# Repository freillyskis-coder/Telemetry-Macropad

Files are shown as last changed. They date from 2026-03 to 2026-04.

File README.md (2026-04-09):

# Telemetry-Macropad
This is a place where I store all of my files for my macropad that has an accelerometer, display, and lights that will show telemetry information for racing.

### What It Does
This macropad has a computer, display, accelerometer, a few lights, and 3 keys. The accelerometer is used to measure acceleration in different directions (duh). That information gets used to display which direction it is accelerating in a traction-circle style display, or in plain number format, on the screen. The lights also indicate what direction the board is accelerating, with one pointing in each cardinal direction for the device. The lights each have two functions, requiring a long or short press. They go like this:
- Switch modes on the display (trac circle, current acceleration numbers, etc) (Short) / Set brightness (Long)
- Recalibration (Short) / Switch Units (g’s vs m/s) (Long)
- Freezes max acceleration (Short) / Reset acceleration (size of the traction circle) (Long)
  
### Why I Built This
I have seen traction circles be used in racing simulators to assist the driver. However, I had never seen one in a real car. I thought it would be really cool to try my hand at designing a device that could display information relevant to racing. In the future, I may add new features such as data collection, slip warnings, etc. 

### Challenges
I haven't done that much design work myself, so this was full of new experiences for me. I have used onshape for 3d cad work before, so it was fun learning how to use fusion (they were pretty similar, at least for what I was doing). 
I also enjoyed learning how to use the KiCAD software. I've used Rapidharness before for electrical work, but it was so cool and different designing a PCB. One of the biggest challenges was the coding, as I've only used Java for my compsci class, and figuring out how to use Github (it required a lot of youtube tutorials and headscratching). Overall, I persisted through and I gained a lot of valuable skills and had a good time!

### Designs
Schematic            |  PCB         |   Case    |   
:-------------------------:|:-------------------------:|:-------------------------:|
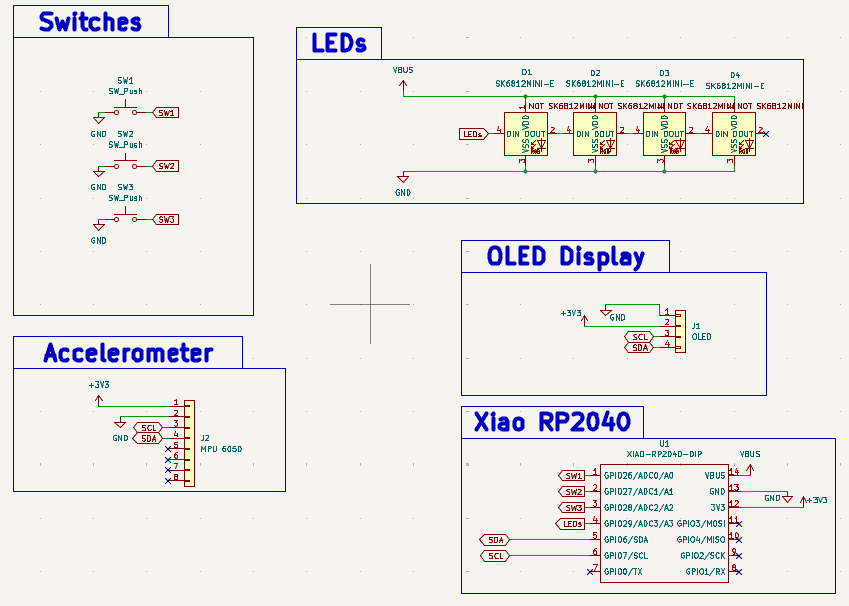
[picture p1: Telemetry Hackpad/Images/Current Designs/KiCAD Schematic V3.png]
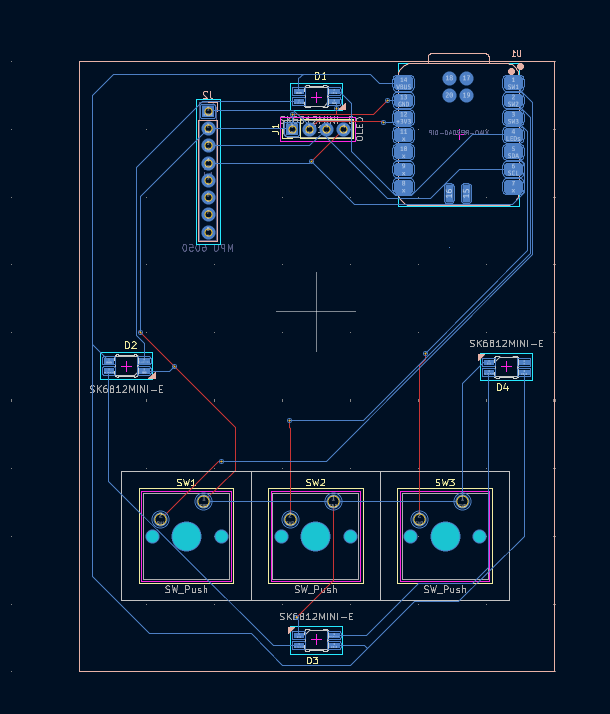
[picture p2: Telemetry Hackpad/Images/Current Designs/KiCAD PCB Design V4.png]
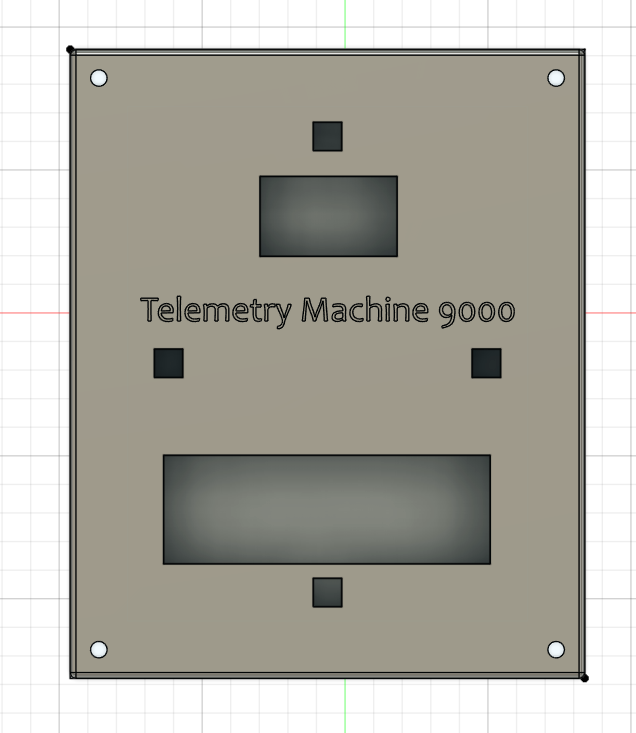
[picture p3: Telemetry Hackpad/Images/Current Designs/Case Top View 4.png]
  |    |   

# Overall Hackpad:

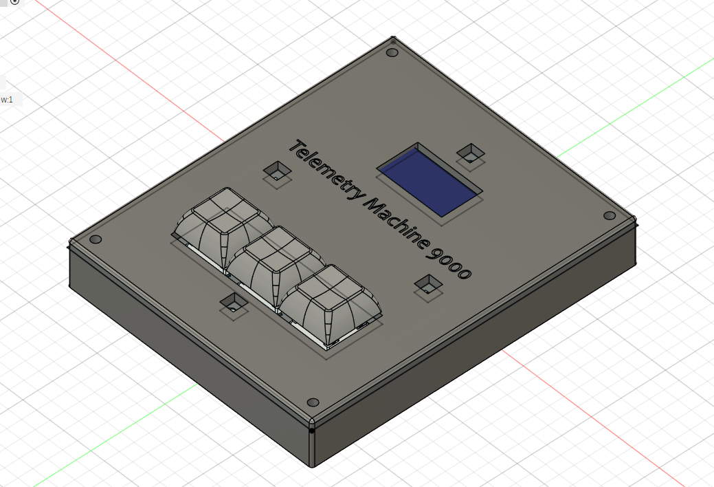
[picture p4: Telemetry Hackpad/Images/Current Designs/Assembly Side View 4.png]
 

### Bill Of Materials

- [4 x SK6812MINI-E](https://www.digikey.com/en/products/detail/adafruit-industries-llc/4960/14302512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) - lights, $2.95
- [1 x XIAO RP2040 DIP](https://www.seeedstudio.com/XIAO-RP2040-v1-0-p-5026.html) - computer, $3.99
- [3 x Cherry MX Switches](https://mechanicalkeyboards.com/products/cherry-mx2a-silent-red-45g-linear?variant=48014625177900) - switches $0.40
- [3 x DSA Black Keycaps](https://thepihut.com/products/black-dsa-keycaps-for-mx-compatible-switches-10-pack) - keycaps (10 pack) $5.80
- [4 x M3x3mm heatset inserts](https://www.adafruit.com/product/4256) - inserts, $5.95 
- [4 x M3x10mm screws](https://www.amazon.com/Screws-Assortment-Machine-Washers-Phillips/dp/B0G9HDWD3K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)   - screws, $3.99
- My PCB, printed
- My 3D printed case

I have an accelerometer and 0.96" display in my designs, but I am not requesting them as I know it they not a part of the kit. I will pay for this myself.
- [1 x MPU 6050](https://www.alibaba.com/product-detail/TZT-1Set-IIC-I2C-GY-521_1600855862949.html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) - accelerometer, $1.45
- [1 x SSD1306 OLED](https://www.alibaba.com/product-detail/0-96-128x64-I2C-IIC-Serial_1601221974195.html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) - display, $2.50

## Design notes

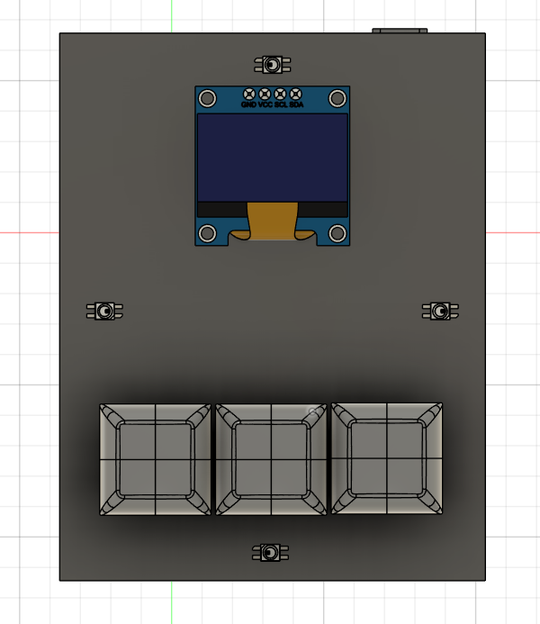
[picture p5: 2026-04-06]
Telemetry Hackpad/Images/Current Designs/PCB Top View 4.png

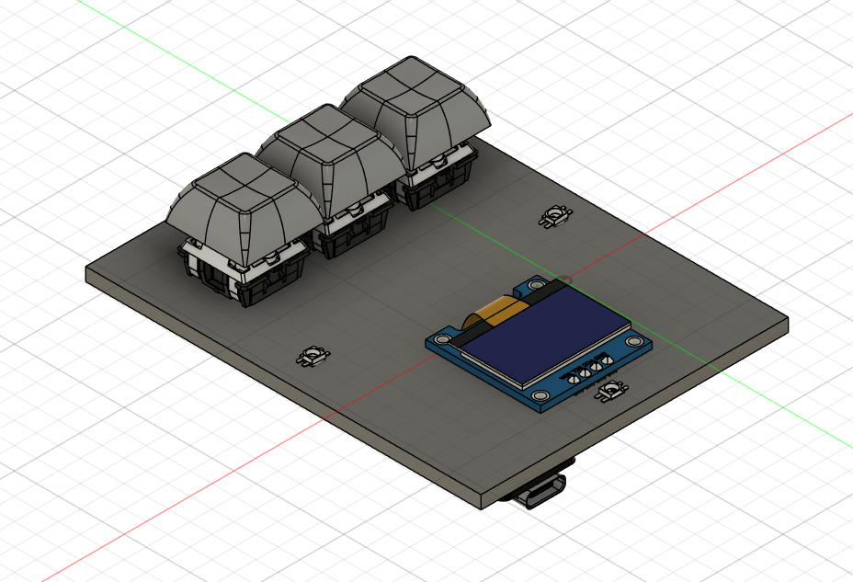
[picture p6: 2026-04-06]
Telemetry Hackpad/Images/Current Designs/PCB Side View 4.png

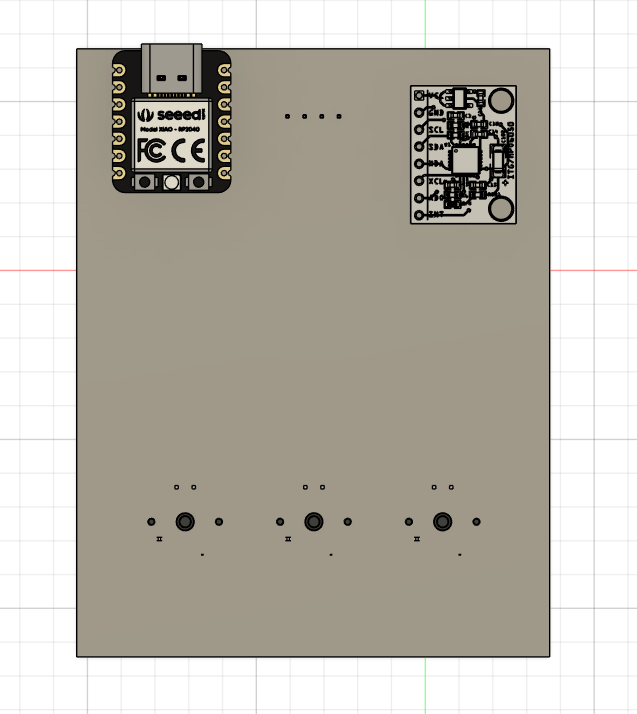
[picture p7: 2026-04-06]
Telemetry Hackpad/Images/Current Designs/PCB Bottom View 4.png

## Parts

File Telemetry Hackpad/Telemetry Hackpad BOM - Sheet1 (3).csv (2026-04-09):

Part | Cost | Link
4 x SK6812MINI-E - lights | $2.95 | https://www.digikey.com/en/products/detail/adafruit-industries-llc/4960/14302512?gclsrc=aw.ds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
XIAO RP2040 DIP - computer | $3.99 | https://www.seeedstudio.com/XIAO-RP2040-v1-0-p-5026.html
3 x Cherry MX Switches - switches | $0.40 | https://mechanicalkeyboards.com/products/cherry-mx2a-silent-red-45g-linear?variant=48014625177900
3 x DSA Black Keycaps - keycaps (10 pack) | $5.80 | https://thepihut.com/products/black-dsa-keycaps-for-mx-compatible-switches-10-pack
4 x M3x3mm heatset inserts | $5.95 | https://www.adafruit.com/product/4256
4 x M3x10mm screws - screws | $3.99 | https://www.amazon.com/Screws-Assortment-Machine-Washers-Phillips/dp/B0G9HDWD3K?s=industrial
My PCB, printed
My 3D printed case
Total: | $23.08
I will purchase the accelerometer myself and display myself because they are not in the kit
MPU 6050 - accelerometer | $1.45 | https://www.alibaba.com/product-detail/TZT-1Set-IIC-I2C-GY-521_1600855862949.html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
SSD1306 OLED - display | $2.50 | https://www.alibaba.com/product-detail/0-96-128x64-I2C-IIC-Serial_1601221974195.html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

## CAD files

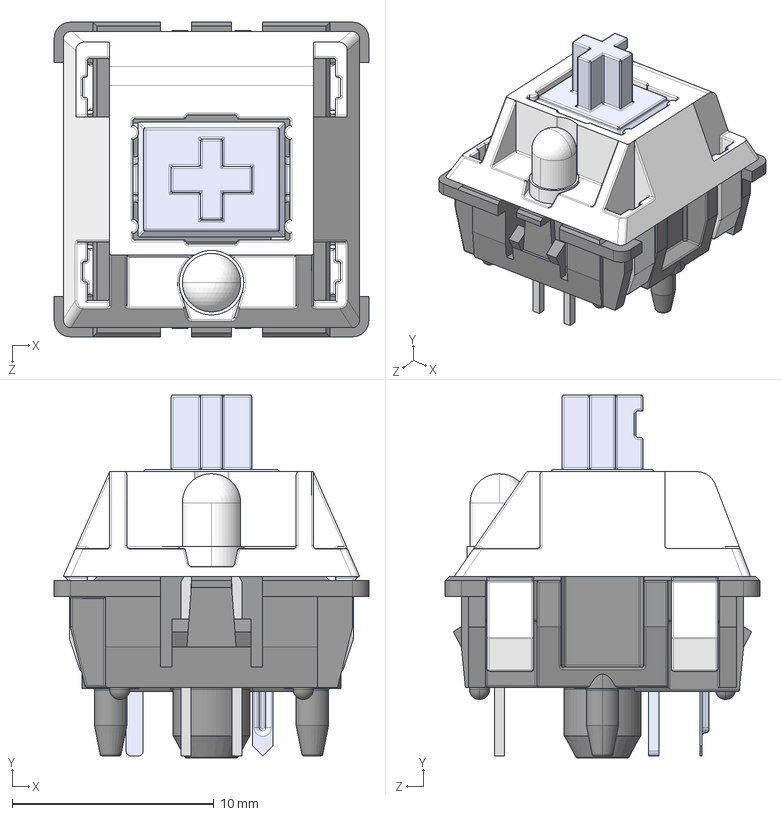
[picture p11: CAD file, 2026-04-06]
Telemetry Hackpad/CAD/Electronics CAD Models/Cherry MX/Cherry MX.STEP
15.6 x 18.0 x 15.6 mm
Bottom
Pulsador
Top
Pieza5^Cherry MX
Pin1
Pin2
Led 3mm_trans

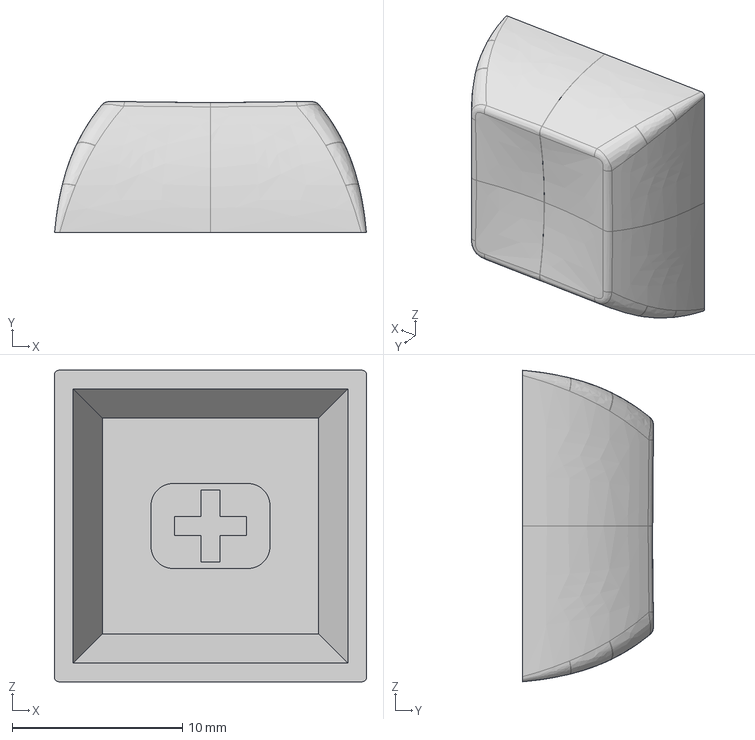
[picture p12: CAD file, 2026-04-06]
Telemetry Hackpad/CAD/Electronics CAD Models/DSA Keycap/DSA_Keycap_CherryMX.step
18.3 x 7.69 x 18.3 mm

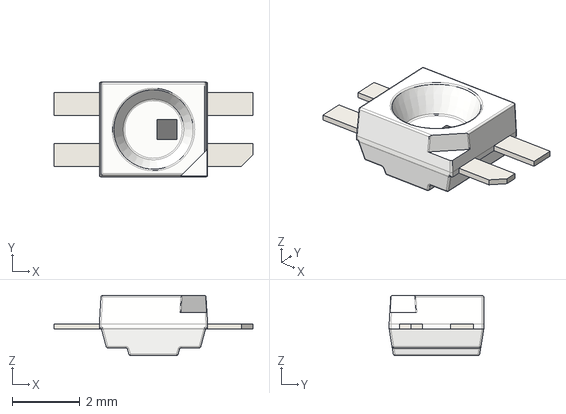
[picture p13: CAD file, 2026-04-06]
Telemetry Hackpad/CAD/Electronics CAD Models/SK6812MINI-E/LED_SK6812MINI-E.step
5.88 x 2.80 x 1.78 mm

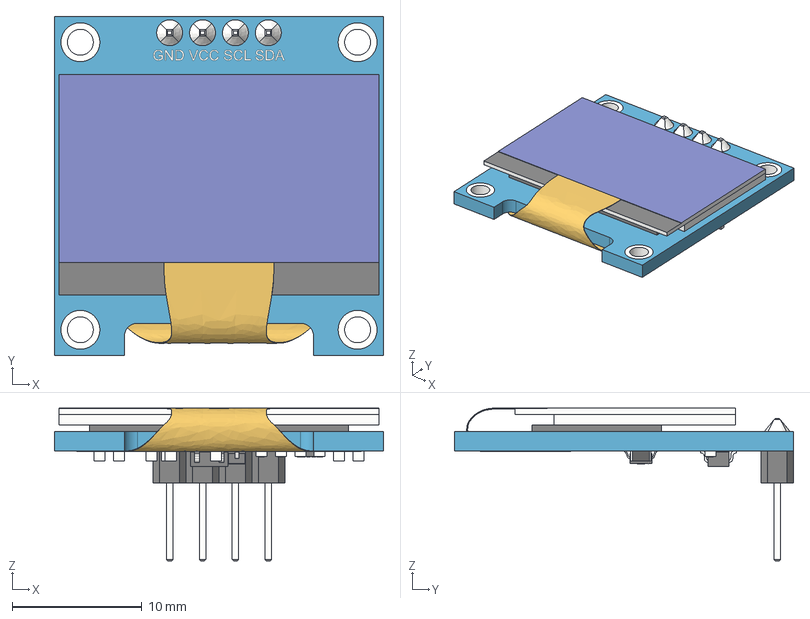
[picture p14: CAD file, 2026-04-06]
Telemetry Hackpad/CAD/Electronics CAD Models/SSD1306 OLED/SSD1306_OLED_Display(128x64).step
25.4 x 26.2 x 11.8 mm
board
screen
pin_header
soldering
smd_capacitor
smd_capacitor (1)
914_smd_resistor
472_smd_resistor x 3
t4_smd_diode
smd_capacitor (2)
smd_capacitor (3)
smd_capacitor (4)
smd_capacitor (5)
smd_capacitor (6)
472_smd_resistor (1)
SOT-23_XC6206 v3
smd_capacitor (7)
flat_cable

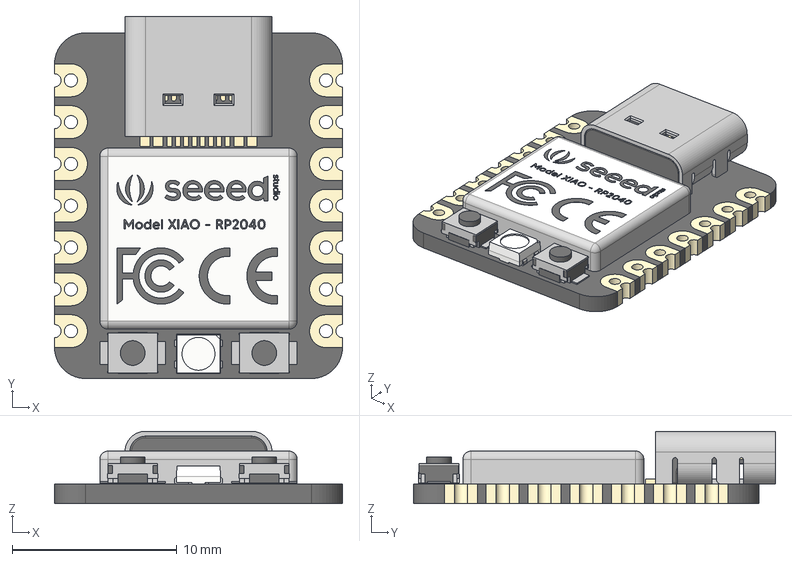
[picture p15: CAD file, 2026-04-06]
Telemetry Hackpad/CAD/Electronics CAD Models/XIAO RP2040/Seeed Studio XIAO RP2040/Seeed Studio XIAO RP2040 v26.step
17.5 x 22.0 x 4.40 mm
type-c v2
smd_button v3
DOUT
DIN
VSS
VDD
smd_button v3(Mirror)

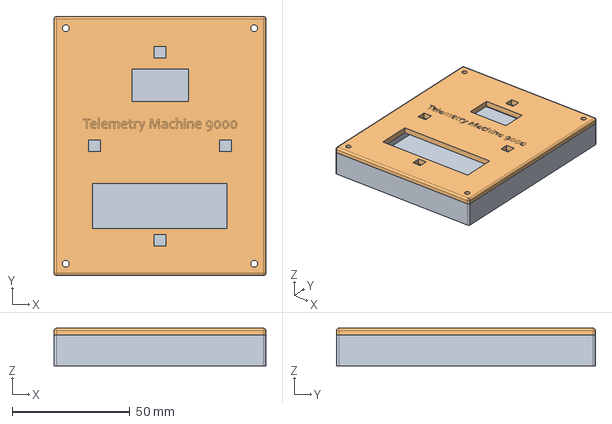
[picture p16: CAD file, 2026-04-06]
Telemetry Hackpad/CAD/Individual Parts/Telemetry Case.step
90.0 x 110.0 x 16.0 mm

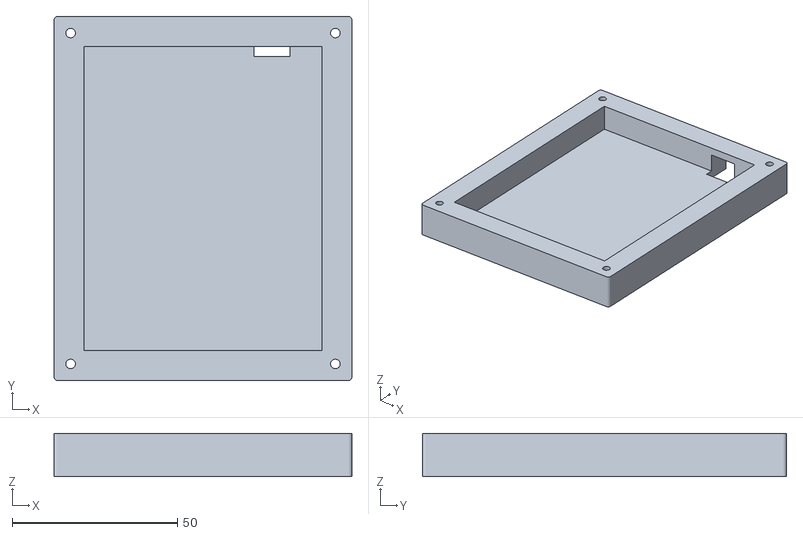
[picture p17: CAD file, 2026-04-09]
Telemetry Hackpad/Production/Bottom Case.stl
90.0 x 110.0 x 13.0

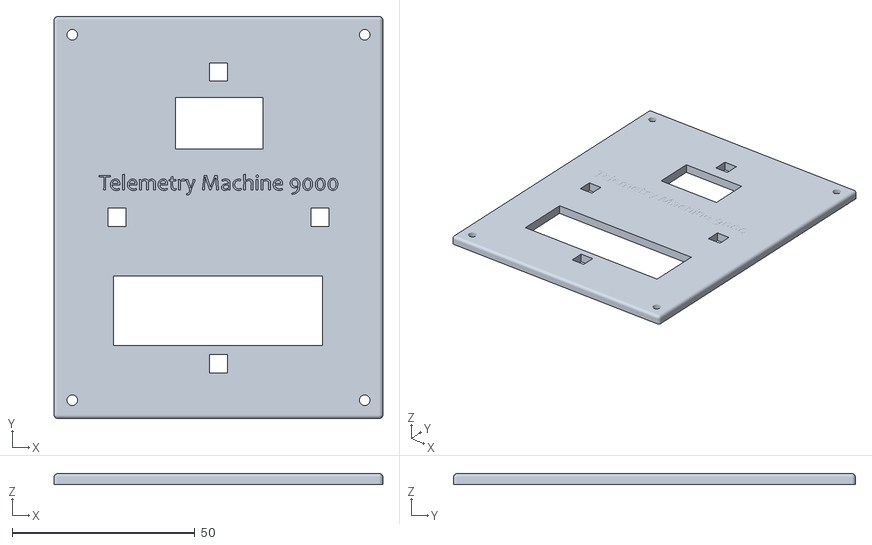
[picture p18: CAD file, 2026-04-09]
Telemetry Hackpad/Production/Top Case.stl
90.0 x 110.0 x 3.00

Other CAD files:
Telemetry Hackpad/CAD/Electronics CAD Models/DSA Keycap/Keycap_adjusted v39.f3d
Telemetry Hackpad/CAD/Electronics CAD Models/SSD1306 OLED/SSD1306_OLED_Display(128x64).f3d
Telemetry Hackpad/CAD/Electronics CAD Models/XIAO RP2040/Seeed Studio XIAO RP2040/Seeed Studio XIAO RP2040 v26.f3d
Telemetry Hackpad/CAD/Individual Parts/Telemetry Case.f3d

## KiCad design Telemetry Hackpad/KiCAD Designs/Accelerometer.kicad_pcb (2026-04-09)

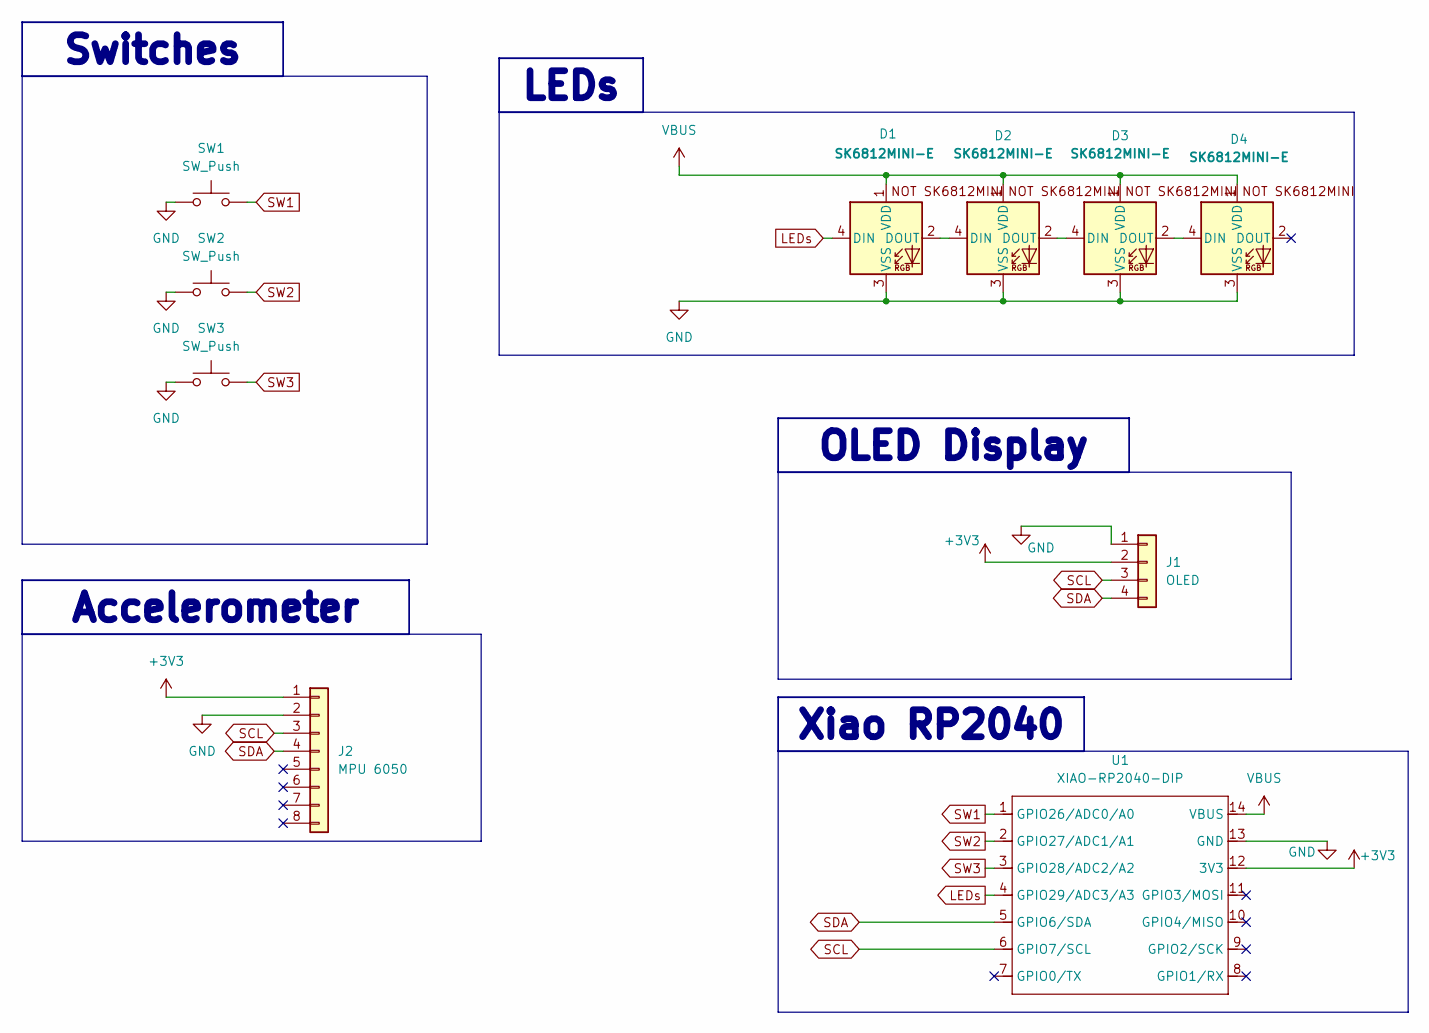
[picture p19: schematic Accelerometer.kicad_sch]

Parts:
D1, D2, D3, D4: SK6812MINI-E; SK6812MINI-E_fixed
J1: OLED; PinHeader_1x04_P2.54mm_Vertical
J2: MPU 6050; PinHeader_1x08_P2.54mm_Vertical
SW1, SW2, SW3: SW_Push; SW_Cherry_MX_1.00u_PCB
U1: XIAO-RP2040-DIP; XIAO-RP2040-SMD

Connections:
+3V3: J1.2 (VDD), J2.1 (VCC), U1.12 (3V3)
GND: D1.3 (VSS), D2.3 (VSS), D3.3 (VSS), D4.3 (VSS), J1.1 (GND), J2.2 (GND), SW1.1, SW2.1, SW3.1, U1.13 (GND)
LEDs: D1.4 (DIN), U1.4 (GPIO29/ADC3/A3)
unnamed: D1.2 (DOUT), D2.4 (DIN)
unnamed: D2.2 (DOUT), D3.4 (DIN)
unnamed: D3.2 (DOUT), D4.4 (DIN)
SCL: J1.3 (SCL), J2.3 (SCL), U1.6 (GPIO7/SCL)
SDA: J1.4 (SDA), J2.4 (SDA), U1.5 (GPIO6/SDA)
SW1: SW1.2, U1.1 (GPIO26/ADC0/A0)
SW2: SW2.2, U1.2 (GPIO27/ADC1/A1)
SW3: SW3.2, U1.3 (GPIO28/ADC2/A2)
VBUS: D1.1 (VDD), D2.1 (VDD), D3.1 (VDD), D4.1 (VDD), U1.14 (VBUS)

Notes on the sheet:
Accelerometer
LEDs
Xiao RP2040
Switches
OLED Display

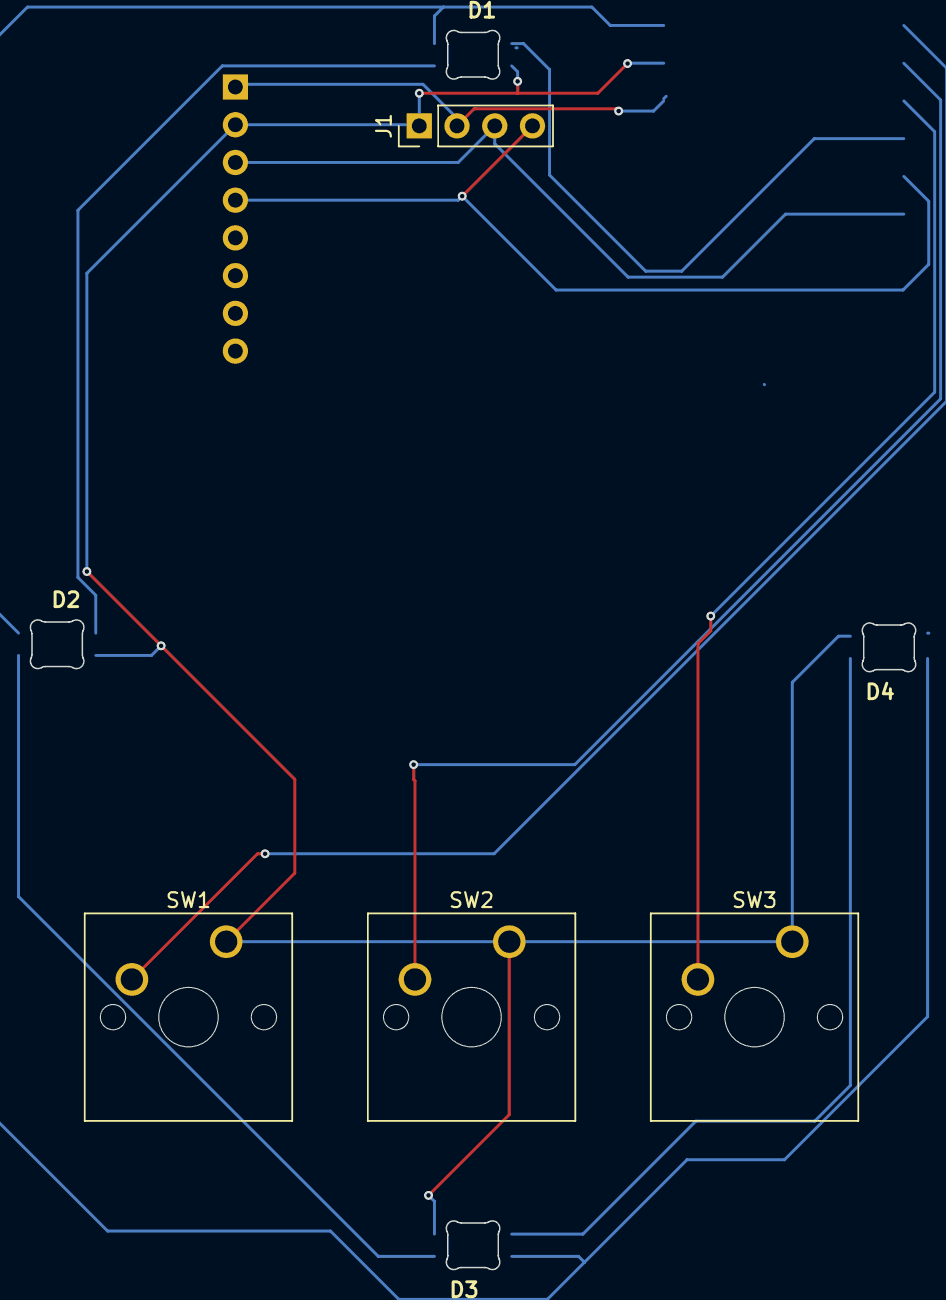
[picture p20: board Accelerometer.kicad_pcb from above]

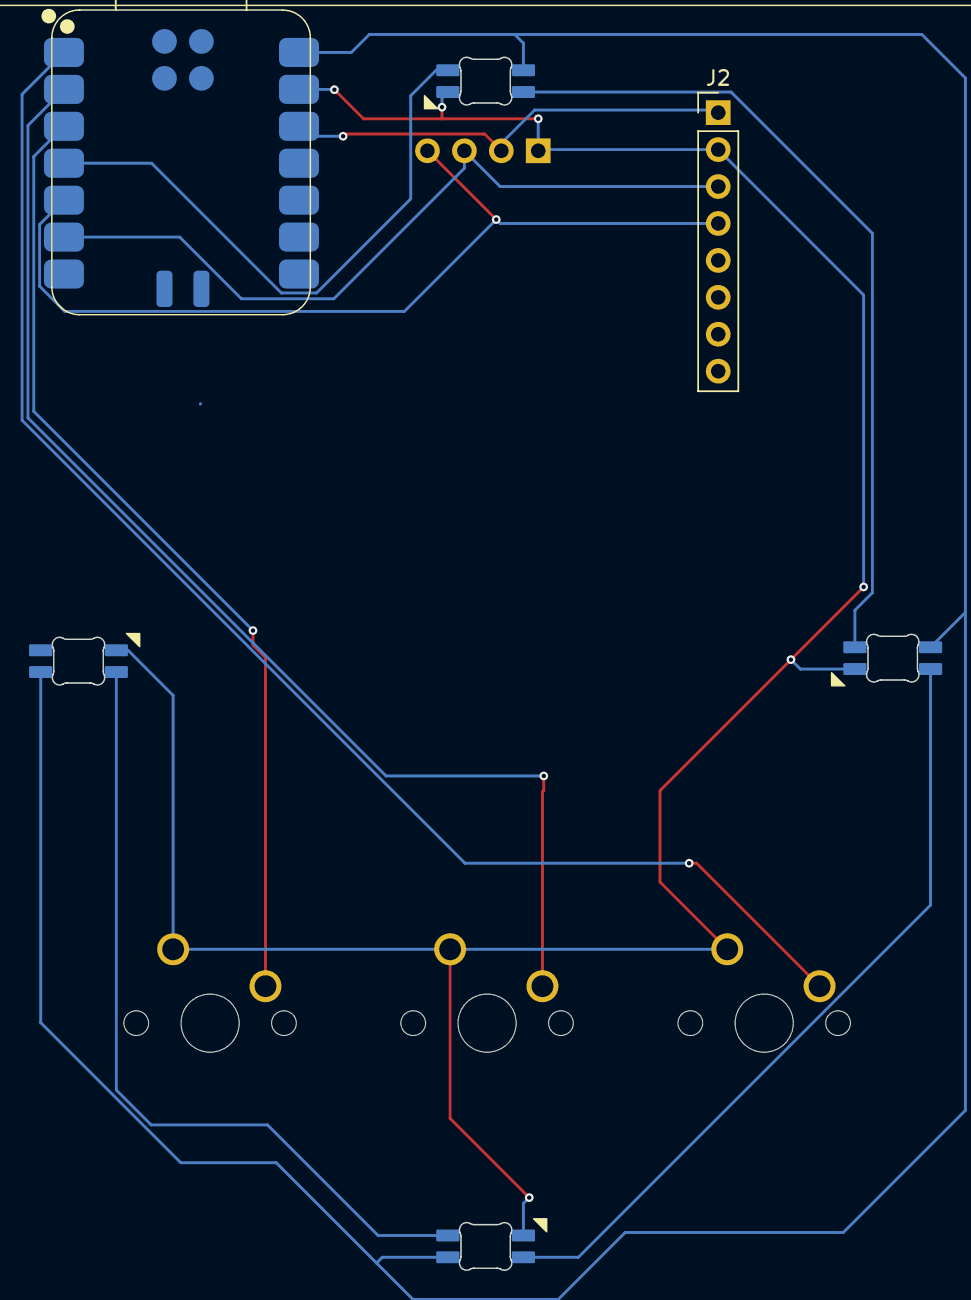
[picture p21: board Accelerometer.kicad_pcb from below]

Board: 2 copper layers, 10 parts (2 on the bottom side), 12 nets.

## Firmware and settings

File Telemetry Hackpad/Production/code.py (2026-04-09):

code.py
# --- Imports ---
import board
import busio
import time
import neopixel
import digitalio
import math
from adafruit_mpu6050 import MPU6050
from adafruit_ssd1306 import SSD1306_I2C
# --- I2C Setup ---
i2c = busio.I2C(board.SCL, board.SDA)

# --- OLED Setup ---
oled = SSD1306_I2C(128, 32, i2c)

# --- Accelerometer Setup ---
mpu = MPU6050(i2c)

# --- LED Setup ---
pixels = neopixel.NeoPixel(board.D2, 4, brightness=0.3, auto_write=False)

# --- Button Setup ---
btn_mode = digitalio.DigitalInOut(board.D3)
btn_mode.direction = digitalio.Direction.INPUT
btn_mode.pull = digitalio.Pull.UP

btn_cal = digitalio.DigitalInOut(board.D4)
btn_cal.direction = digitalio.Direction.INPUT
btn_cal.pull = digitalio.Pull.UP

btn_max = digitalio.DigitalInOut(board.D5)
btn_max.direction = digitalio.Direction.INPUT
btn_max.pull = digitalio.Pull.UP
# --- State Variables ---

# Display modes: 0 = traction circle, 1 = acceleration numbers
display_mode = 0

# Units: 0 = g's, 1 = m/s²
units = 0

# Brightness levels (0.1 to 1.0)
brightness_levels = [0.1, 0.3, 0.6, 1.0]
brightness_index = 1

# Acceleration tracking
max_accel = 0.0
frozen_max = False
zero_offset = [0.0, 0.0, 0.0]

# Button timing (for long press detection)
LONG_PRESS_TIME = 0.8
btn_mode_held = False
btn_cal_held = False
btn_max_held = False
btn_mode_press_time = 0
btn_cal_press_time = 0
btn_max_press_time = 0
# --- LED Position Map ---
# Matches KiCad wiring: D1=top, D2=left, D3=bottom, D4=right
LED_TOP = 0
LED_BOTTOM = 2
LED_LEFT = 1
LED_RIGHT = 3
# --- Acceleration to Color ---
def accel_to_color(strength, is_max):
    if is_max:
        return (128, 0, 128)  # Purple for max
    elif strength > 0.75:
        return (255, 0, 0)    # Red
    elif strength > 0.5:
        return (255, 165, 0)  # Orange/Yellow
    elif strength > 0.25:
        return (0, 255, 0)    # Green
    else:
        return (0, 0, 0)      # Off
# --- Update LEDs ---
def update_leds(x, y, max_accel):
    # Turn all LEDs off to start
    pixels.fill((0, 0, 0))
    
    # Calculate total acceleration strength (0.0 to 1.0)
    total = max_accel if max_accel > 0 else 1.0
    
    # Forward/backward (Y axis)
    if y > 0.1:
        strength = min(y / total, 1.0)
        is_max = (y >= max_accel)
        pixels[LED_TOP] = accel_to_color(strength, is_max)
    elif y < -0.1:
        strength = min(abs(y) / total, 1.0)
        is_max = (abs(y) >= max_accel)
        pixels[LED_BOTTOM] = accel_to_color(strength, is_max)
    
    # Left/right (X axis)
    if x > 0.1:
        strength = min(x / total, 1.0)
        is_max = (x >= max_accel)
        pixels[LED_RIGHT] = accel_to_color(strength, is_max)
    elif x < -0.1:
        strength = min(abs(x) / total, 1.0)
        is_max = (abs(x) >= max_accel)
        pixels[LED_LEFT] = accel_to_color(strength, is_max)
    
    pixels.show()
# --- Button Handler ---
def check_buttons():
    global display_mode, units, brightness_index, max_accel, frozen_max, zero_offset
    global btn_mode_held, btn_cal_held, btn_max_held
    global btn_mode_press_time, btn_cal_press_time, btn_max_press_time

    current_time = time.monotonic()

    # --- Button 1 (Mode) ---
    if not btn_mode.value:  # Button is pressed
        if not btn_mode_held:
            btn_mode_held = True
            btn_mode_press_time = current_time
    else:  # Button is released
        if btn_mode_held:
            held_duration = current_time - btn_mode_press_time
            if held_duration >= LONG_PRESS_TIME:
                # Long press - cycle brightness
                brightness_index = (brightness_index + 1) % len(brightness_levels)
                pixels.brightness = brightness_levels[brightness_index]
            else:
                # Short press - cycle display mode
                display_mode = (display_mode + 1) % 2
            btn_mode_held = False

    # --- Button 2 (Calibration) ---
    if not btn_cal.value:
        if not btn_cal_held:
            btn_cal_held = True
            btn_cal_press_time = current_time
    else:
        if btn_cal_held:
            held_duration = current_time - btn_cal_press_time
            if held_duration >= LONG_PRESS_TIME:
                # Long press - switch units
                units = (units + 1) % 2
            else:
                # Short press - zero calibration
                x, y, z = mpu.acceleration
                zero_offset[0] = x
                zero_offset[1] = y
                zero_offset[2] = z
            btn_cal_held = False

    # --- Button 3 (Max) ---
    if not btn_max.value:
        if not btn_max_held:
            btn_max_held = True
            btn_max_press_time = current_time
    else:
        if btn_max_held:
            held_duration = current_time - btn_max_press_time
            if held_duration >= LONG_PRESS_TIME:
                # Long press - reset max acceleration
                max_accel = 0.0
                frozen_max = False
            else:
                # Short press - freeze/unfreeze max
                frozen_max = not frozen_max
            btn_max_held = False
# --- Draw Acceleration Numbers ---
def draw_numbers(x, y, z):
    oled.fill(0)  # Clear screen
    
    if units == 0:  # g's
        oled.text("X: {:.2f}g".format(x), 0, 0, 1)
        oled.text("Y: {:.2f}g".format(y), 0, 11, 1)
        oled.text("Z: {:.2f}g".format(z), 0, 22, 1)
    else:  # m/s²
        oled.text("X: {:.2f}m/s2".format(x), 0, 0, 1)
        oled.text("Y: {:.2f}m/s2".format(y), 0, 11, 1)
        oled.text("Z: {:.2f}m/s2".format(z), 0, 22, 1)
    
    oled.show()

# --- Draw Traction Circle ---
def draw_traction_circle(x, y, max_accel):
    oled.fill(0)  # Clear screen
    
    # Circle center and radius
    cx = 64
    cy = 16
    radius = 14
    
    # Draw the outer circle
    for angle in range(0, 360, 5):
        px = int(cx + radius * math.cos(math.radians(angle)))
        py = int(cy + radius * math.sin(math.radians(angle)))
        oled.pixel(px, py, 1)
    
    # Draw crosshairs
    oled.line(cx - radius, cy, cx + radius, cy, 1)  # Horizontal
    oled.line(cx, cy - radius, cx, cy + radius, 1)  # Vertical
    
    # Draw the dot representing current acceleration
    total = max_accel if max_accel > 0 else 1.0
    dot_x = int(cx + (x / total) * radius)
    dot_y = int(cy - (y / total) * radius)
    
    # Keep dot inside circle
    dot_x = max(cx - radius, min(cx + radius, dot_x))
    dot_y = max(cy - radius, min(cy + radius, dot_y))
    
    # Draw dot as a small cross
    oled.pixel(dot_x, dot_y, 1)
    oled.pixel(dot_x + 1, dot_y, 1)
    oled.pixel(dot_x - 1, dot_y, 1)
    oled.pixel(dot_x, dot_y + 1, 1)
    oled.pixel(dot_x, dot_y - 1, 1)
    
    # Show max acceleration value at bottom
    oled.text("Max:{:.2f}g".format(max_accel), 0, 25, 1)
    
    oled.show()
# --- Main Loop ---
while True:
    # --- Read Accelerometer ---
    x_raw, y_raw, z_raw = mpu.acceleration  # Always in m/s²
    
    # Apply zero offset
    x_raw -= zero_offset[0]
    y_raw -= zero_offset[1]
    z_raw -= zero_offset[2]
    
    # Convert units
    if units == 0:  # g's
        x = x_raw / 9.81
        y = y_raw / 9.81
        z = z_raw / 9.81
    else:  # m/s²
        x = x_raw
        y = y_raw
        z = z_raw
    
    # --- Update Max Acceleration ---
    if not frozen_max:
        current_accel = (x**2 + y**2) ** 0.5
        if current_accel > max_accel:
            max_accel = current_accel
    
    # --- Update Display ---
    if display_mode == 0:
        draw_traction_circle(x, y, max_accel)
    else:
        draw_numbers(x, y, z)
    
    # --- Update LEDs ---
    update_leds(x, y, max_accel)
    
    # --- Check Buttons ---
    check_buttons()
    
    # --- Small delay ---
    time.sleep(0.05)

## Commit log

2026-03-24 Added all macropad files
    [KiCAD PCB Files.kicad_pcb, KiCAD PCB Files.kicad_sch, Telemetry Assembly.f3z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]
2026-03-24 Rename KiCAD PCB.png to KiCAD_PCB.png
2026-03-24 Rename KiCAD Schematic.png to KiCAD_Schematic.png
2026-03-24 Update README.md BOM to correctly link the items
2026-03-24 Added the correct KiCAD files
    [Telemetry Macropad.kicad_pcb]
2026-03-24 Hopefully these are the correct files
    I believe that, before uploading my KiCAD schematic and PCB files, in trying to change the name of the project, I accidentally messed up the linking between them or something. However, I believe that these are the correct files and they should link properly. They are called "accelerometer." I also lost all of my backups because of this.
    [Accelerometer.kicad_pcb, Accelerometer.kicad_sch]
2026-03-25 Added new and improved KiCAD Schematic
    Updated by vmshade, another hackclubber who I met on the slack
2026-03-25 Update README.md to include BOM pricing
2026-03-25 Added all complete files for my KiCAD designs
    [Accelerometer.kicad_pcb, Accelerometer.kicad_sch]
2026-03-29 Added files to repository
    [Accelerometer.kicad_pcb, Accelerometer.kicad_sch]
2026-04-06 Adding files
    [Accelerometer.kicad_pcb, Accelerometer.kicad_sch, Cherry MX.STEP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]
2026-04-07 Update Telemetry Hackpad BOM - Sheet1.csv
    [Telemetry Hackpad BOM - Sheet1.csv]
2026-04-07 Update Telemetry Hackpad BOM - Sheet1 (2).csv
    [Telemetry Hackpad BOM - Sheet1 (2).csv]
2026-04-07 Rearranged files
    [Accelerometer.kicad_pcb, Accelerometer.kicad_sch, Cherry MX.STEP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]
2026-04-09 Added production folders
    Moved items around and added shipping routes for various files
    [Accelerometer-B_Cu.gbl, Accelerometer-B_Mask.gbs, Accelerometer-B_Paste.gbp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]
2026-04-09 Update Telemetry Hackpad BOM - Sheet1 (3).csv
    [Telemetry Hackpad BOM - Sheet1 (3).csv]
